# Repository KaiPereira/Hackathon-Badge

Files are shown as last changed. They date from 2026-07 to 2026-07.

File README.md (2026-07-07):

# Hackathon Badges

These are alchemical, cosmological, PCB hackathon badges I designed in a day for the Fallout hackathon in Shenzhen. Powered by the CH32 MCU, they stack ontop of each other using testpoints and shine through each other to create a sun effect and have cool designs on them!






## Manufacturing

If you're bored and want to manufacture the boards, all of their production files are in their relative folder. I'd suggest getting the boards from JLCPCB with ENIG, and then buying the components from LCSC and hand soldering! 

All the design files are also open-source if you want to make modifications so that they're unique to you, so just go crazy!!

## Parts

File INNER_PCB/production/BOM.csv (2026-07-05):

Id | Designator | Footprint | Quantity | Designation | Supplier and ref
1 | C3 | C_0402_1005Metric | 1 | 100nF
2 | D1, D2, D3, D4, D5, D6, D7, D8, D9, D10, D11, D12, D13, D14, D15, D16 | LED_0603_1608Metric | 16 | KT-0603Y
3 | J1 | PinHeader_1x03_P2.54mm_Vertical | 1 | Conn_01x03
4 | J2 | PinHeader_1x02_P2.54mm_Vertical | 1 | Conn_01x02
5 | R1 | R_0402_1005Metric | 1 | 1k
6 | R2, R3, R4, R5, R6, R7, R8, R9, R10, R11, R12, R13, R14, R15, R16, R17 | R_0402_1005Metric | 16 | 2k
7 | TP1, TP2, TP3, TP4, TP5, TP6, TP7, TP8 | TestPoint_Pad_3.0x3.0mm | 8 | TestPoint
8 | U2 | QFN-20-1EP_3x3mm_P0.4mm_EP1.65x1.65mm_ThermalVias | 1 | CH32V003FxUx

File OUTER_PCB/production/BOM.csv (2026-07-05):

Id | Designator | Footprint | Quantity | Designation | Supplier and ref
1 | D1, D2, D3, D4, D5, D6, D7, D8, D9, D10, D11, D12, D13, D14 | LED_WS2812B-2020_PLCC4_2.0x2.0mm | 14 | WS2812B-2020
2 | TP1, TP2, TP3, TP4 | TestPoint_Pad_4.0x4.0mm | 4 | TestPoint

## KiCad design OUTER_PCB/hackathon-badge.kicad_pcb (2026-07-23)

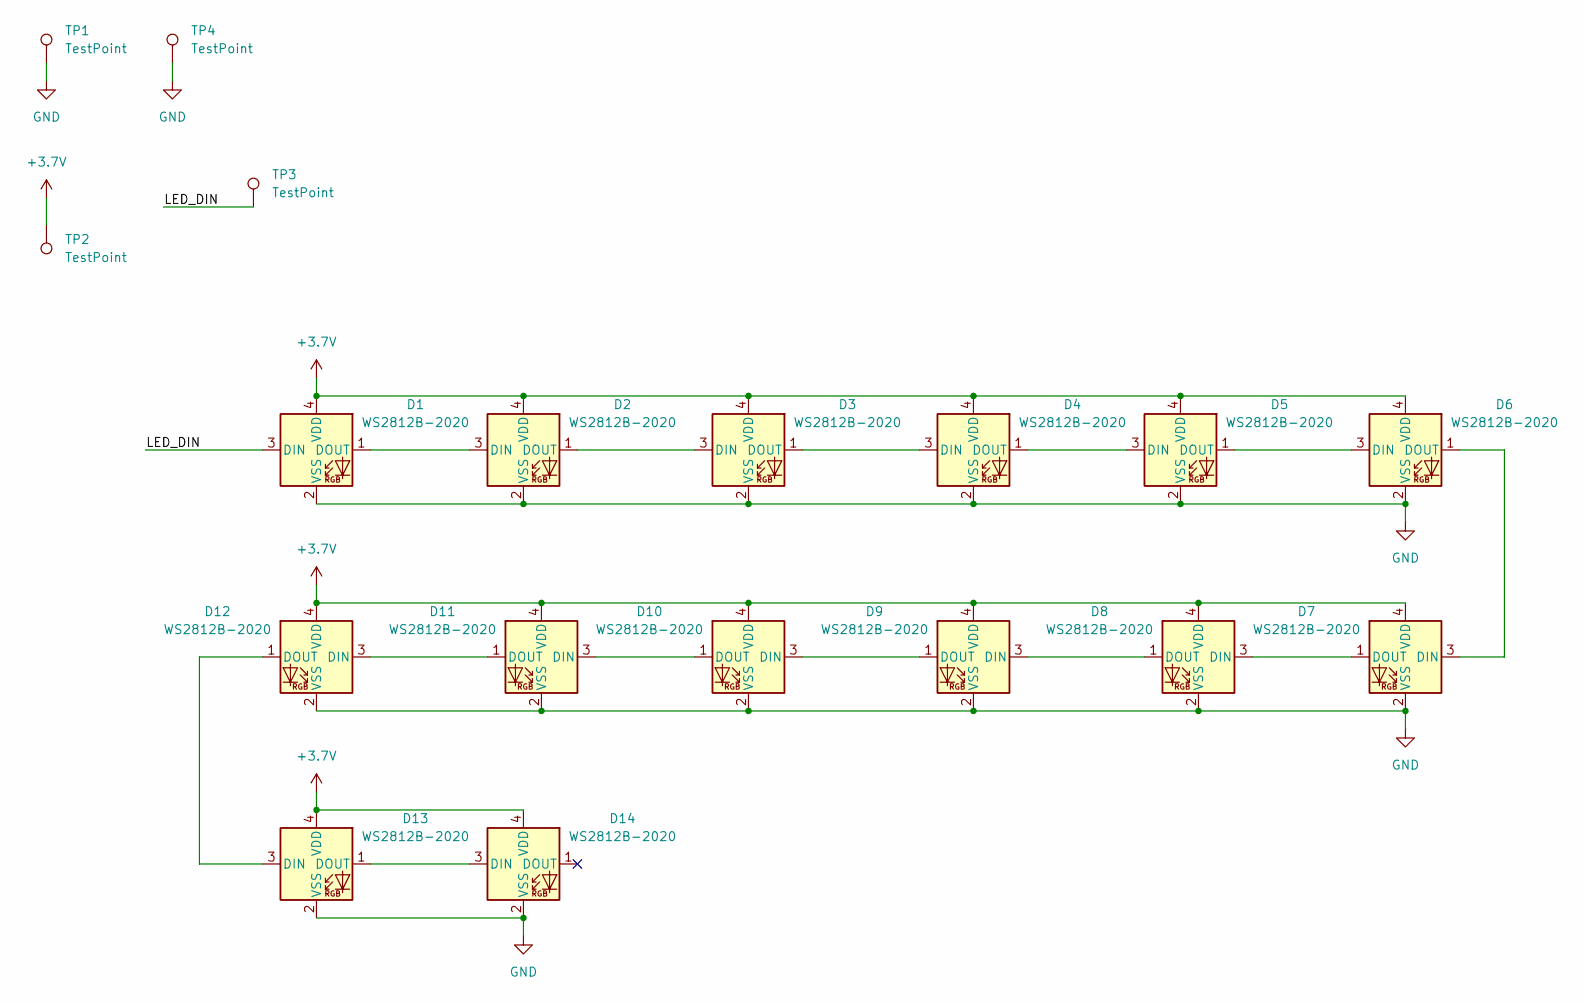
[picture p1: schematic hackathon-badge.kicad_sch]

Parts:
D1, D2, D3, D4, D5, D6, D7, D8, D9, D10, D11, D12, D13, D14: WS2812B-2020; LED_WS2812B-2020_PLCC4_2.0x2.0mm
TP1, TP2, TP3, TP4: TestPoint; TestPoint_Pad_4.0x4.0mm

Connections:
+3.7V: D1.4 (VDD), D2.4 (VDD), D3.4 (VDD), D4.4 (VDD), D5.4 (VDD), D6.4 (VDD), D7.4 (VDD), D8.4 (VDD), D9.4 (VDD), D10.4 (VDD), D11.4 (VDD), D12.4 (VDD), D13.4 (VDD), D14.4 (VDD), TP2.1 (1_1)
/LED_DIN: D1.3 (DIN), TP3.1 (1_1)
GND: D1.2 (VSS), D2.2 (VSS), D3.2 (VSS), D4.2 (VSS), D5.2 (VSS), D6.2 (VSS), D7.2 (VSS), D8.2 (VSS), D9.2 (VSS), D10.2 (VSS), D11.2 (VSS), D12.2 (VSS), D13.2 (VSS), D14.2 (VSS), TP1.1 (1_1), TP4.1 (1_1)
unnamed: D1.1 (DOUT), D2.3 (DIN)
unnamed: D2.1 (DOUT), D3.3 (DIN)
unnamed: D3.1 (DOUT), D4.3 (DIN)
unnamed: D4.1 (DOUT), D5.3 (DIN)
unnamed: D5.1 (DOUT), D6.3 (DIN)
unnamed: D6.1 (DOUT), D7.3 (DIN)
unnamed: D7.1 (DOUT), D8.3 (DIN)
unnamed: D8.1 (DOUT), D9.3 (DIN)
unnamed: D9.1 (DOUT), D10.3 (DIN)
unnamed: D10.1 (DOUT), D11.3 (DIN)
unnamed: D11.1 (DOUT), D12.3 (DIN)
unnamed: D12.1 (DOUT), D13.3 (DIN)
unnamed: D13.1 (DOUT), D14.3 (DIN)

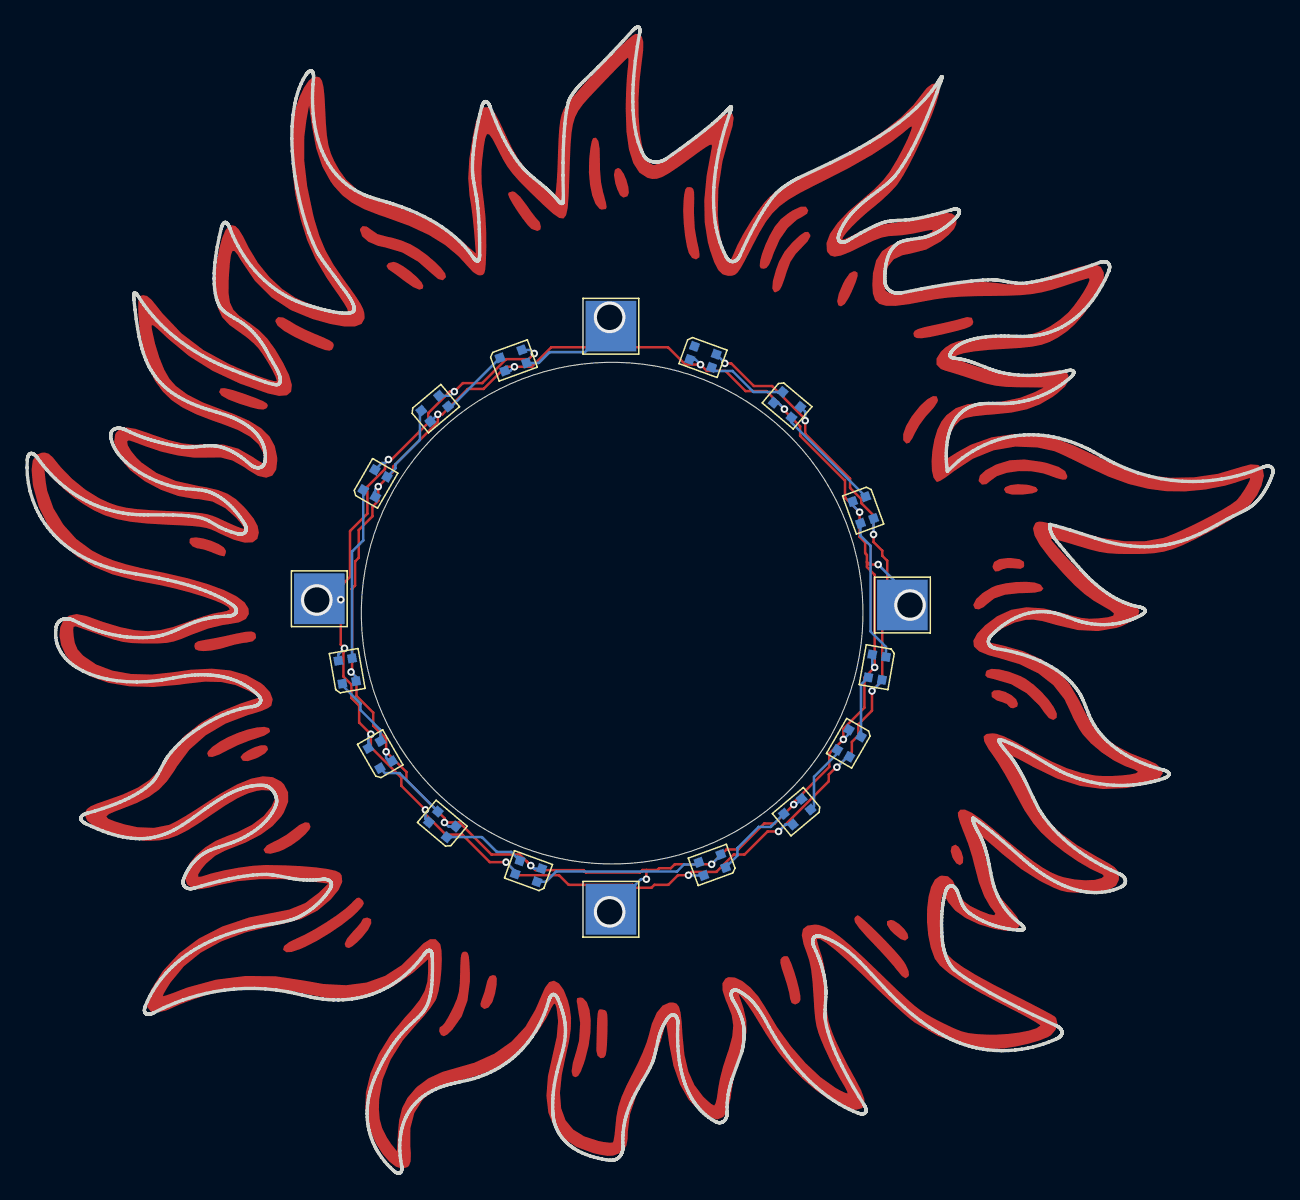
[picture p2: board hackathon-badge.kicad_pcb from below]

Board: 2 copper layers, 98.3 x 90.4 mm, 18 parts (18 on the bottom side), 16 nets.

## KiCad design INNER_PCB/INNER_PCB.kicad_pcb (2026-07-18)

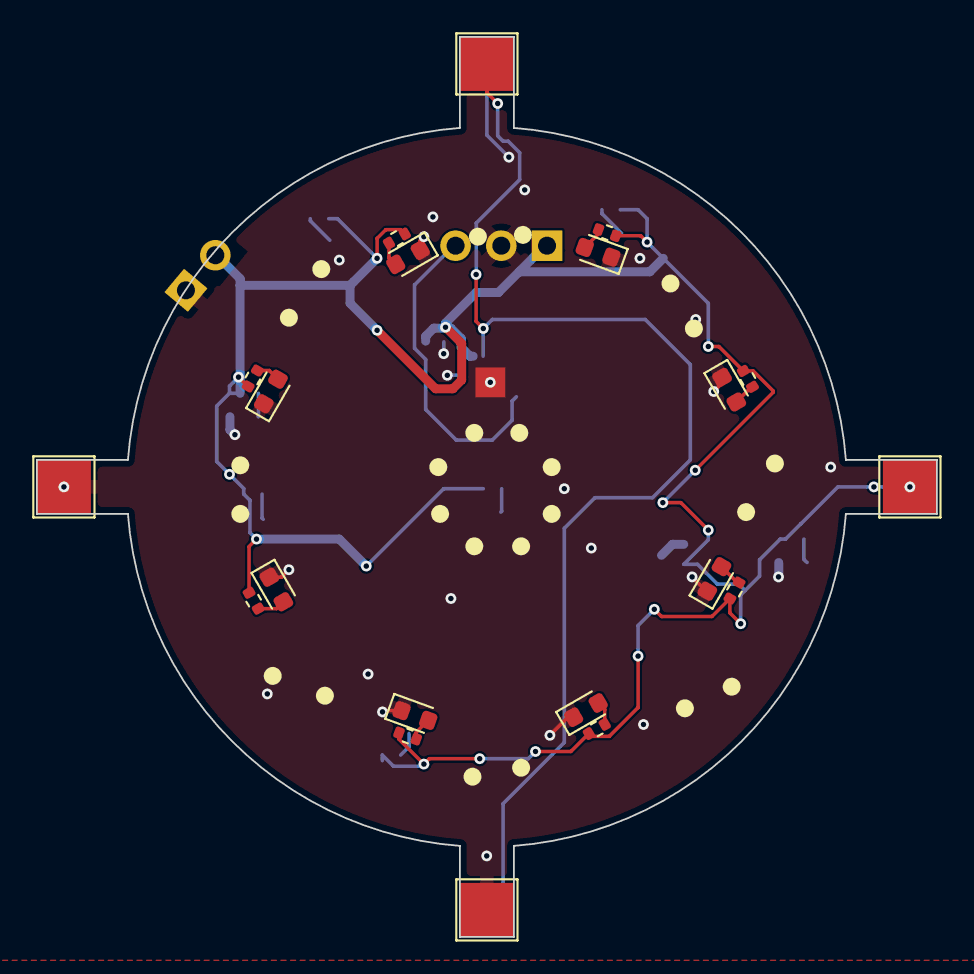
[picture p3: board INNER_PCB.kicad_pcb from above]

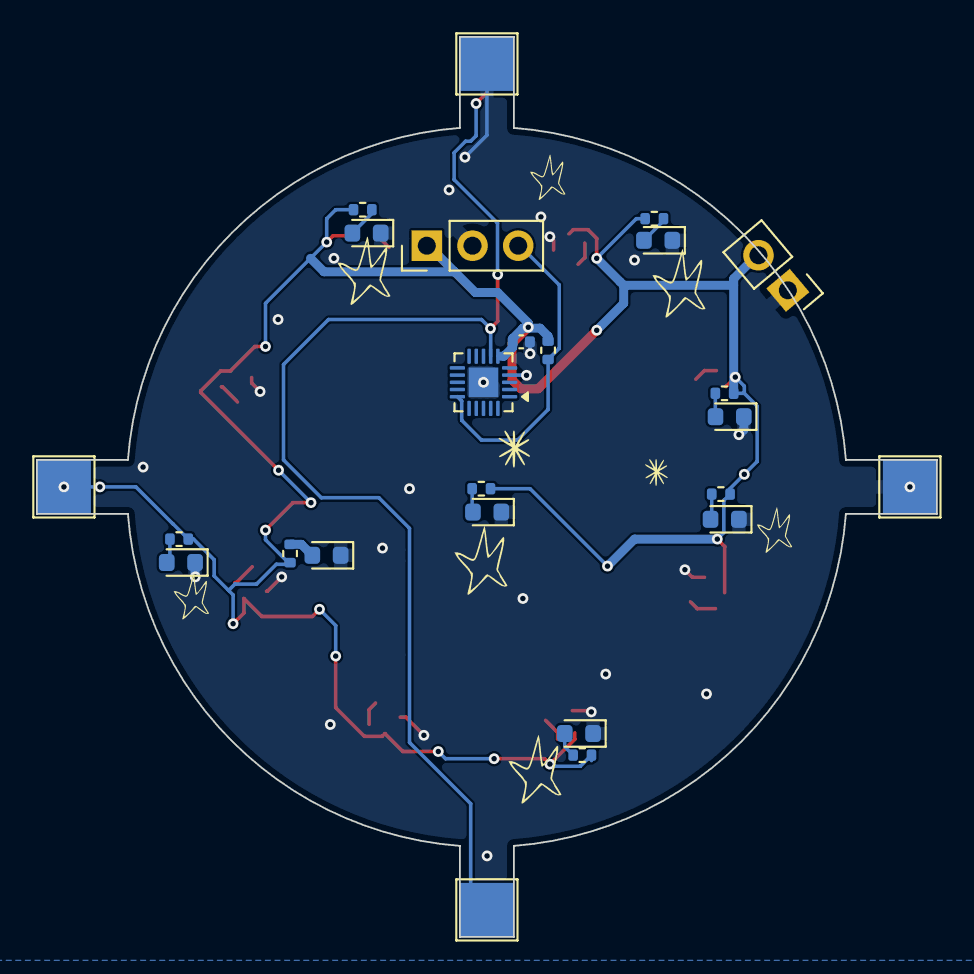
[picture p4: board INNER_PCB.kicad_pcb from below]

Board: 2 copper layers, 50.0 x 50.0 mm, 45 parts (25 on the bottom side), 20 nets.

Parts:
C3: 100nF; C_0402_1005Metric
D1, D2, D3, D4, D5, D6, D7, D8, D9, D10, D11, D12, D13, D14, D15, D16: KT-0603Y; LED_0603_1608Metric
J1: Conn_01x03; PinHeader_1x03_P2.54mm_Vertical
J2: Conn_01x02; PinHeader_1x02_P2.54mm_Vertical
R1: 1k; R_0402_1005Metric
R2, R3, R4, R5, R6, R7, R8, R9, R10, R11, R12, R13, R14, R15, R16, R17: 2k; R_0402_1005Metric
TP1, TP2, TP3, TP4, TP5, TP6, TP7, TP8: TestPoint; TestPoint_Pad_3.0x3.0mm
U2: CH32V003FxUx; QFN-20-1EP_3x3mm_P0.4mm_EP1.65x1.65mm_ThermalVias

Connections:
+3.7V: C3.1, J1.1, J2.2, R1.1, R2.1, R3.1, R4.1, R5.1, R6.1, R7.1, R8.1, R9.1, R10.1, R11.1, R12.1, R13.1, R14.1, R15.1, R16.1, R17.1, TP4.1 (1_1), TP8.1 (1_1), U2.6 (VDD)
/LED_DOUT: TP3.1 (1_1), TP6.1 (1_1), U2.7 (PC0)
/SWIO: J1.3, R1.2, U2.15 (SWIO)
GND: C3.2, D1.1 (K), D2.1 (K), D3.1 (K), D4.1 (K), D5.1 (K), D6.1 (K), D7.1 (K), D8.1 (K), D9.1 (K), D10.1 (K), D11.1 (K), D12.1 (K), D13.1 (K), D14.1 (K), D15.1 (K), D16.1 (K), J1.2, J2.1, TP1.1 (1_1), TP2.1 (1_1), TP5.1 (1_1), TP7.1 (1_1), U2.4 (VSS), U2.21 (VSS)
unnamed: D1.2 (A), R2.2
unnamed: D2.2 (A), R3.2
unnamed: D3.2 (A), R4.2
unnamed: D4.2 (A), R5.2
unnamed: D5.2 (A), R6.2
unnamed: D6.2 (A), R7.2
unnamed: D7.2 (A), R8.2
unnamed: D8.2 (A), R9.2
unnamed: D9.2 (A), R10.2
unnamed: D10.2 (A), R11.2
unnamed: D11.2 (A), R12.2
unnamed: D12.2 (A), R13.2
unnamed: D13.2 (A), R14.2
unnamed: D14.2 (A), R15.2
unnamed: D15.2 (A), R16.2
unnamed: D16.2 (A), R17.2

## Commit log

2026-07-02 whoops organizing
    [hackathon-badge.kicad_pcb, hackathon-badge.kicad_sch]
2026-07-02 removing submodule
    [hackathon-badge.kicad_pcb, hackathon-badge.kicad_sch]
2026-07-02 starting on inner PCB
    [INNER_PCB.kicad_pcb, INNER_PCB.kicad_sch, designators.csv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]
2026-07-02 finished the outer board
    [hackathon-badge.kicad_pcb, hackathon-badge.kicad_sch]
2026-07-02 finished second PCB
    [INNER_PCB.kicad_pcb, INNER_PCB.kicad_sch, hackathon-badge.kicad_pcb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]
2026-07-02 added the second side to the second PCB
    [INNER_PCB.kicad_pcb, INNER_PCB.kicad_sch]
2026-07-05 some more art for the inner badge
    [BOM.csv, INNER_PCB.kicad_pcb, designators.csv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]
2026-07-05 fab files
    [.step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]
2026-07-23 modifying the external part of the badge so that JLC doesn't get mad at me
    [hackathon-badge-B_Cu.gbr, hackathon-badge-B_Mask.gbr, hackathon-badge-B_Paste.gbr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]
2026-07-23 another update
    [hackathon-badge.kicad_pcb]
